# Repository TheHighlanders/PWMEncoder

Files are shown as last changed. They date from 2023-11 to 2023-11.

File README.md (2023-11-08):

# A Custom PWM Encoder for FRC
This encoder connects to a SparkMAX Motor Controller, using the Data Port. This encoder was designed with use on Swerve Drive Specialties Mk 4 Modules, with NEOs. 

These utilize the AS5047 chip to read a rotating magnetic field, and convert that to a PWM output.

Included in this repo are the KiCAD project files, as well as STEP file for the board, and 2 parts of a case that we used to mount these encoders.

## Important Notes

### Data Port Connector
In the project files, the Data Port connector is included on the incorrect side of the board. The pinouts for the board are correct, the only change that needs to be made if you use these is in assembly, the connector should be mounted on the top side (with the LED) of the board, and the notch should face away from the encoder IC.

### Programming the IC
The AS5047 encoder used here requires a programming process to output a PWM signal. A script to do this via an Arduino can be found here: [Programming Script](https://github.com/TheHighlanders/AS5047ProgrammingScript)

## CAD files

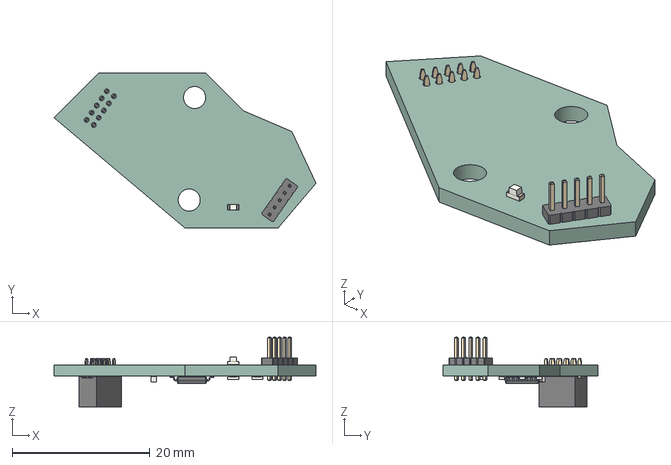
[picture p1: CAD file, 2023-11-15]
FRC6201PWMEncoder/6201PWM.step
38.0 x 22.5 x 10.1 mm
FRC6201PWMEncoder PCB

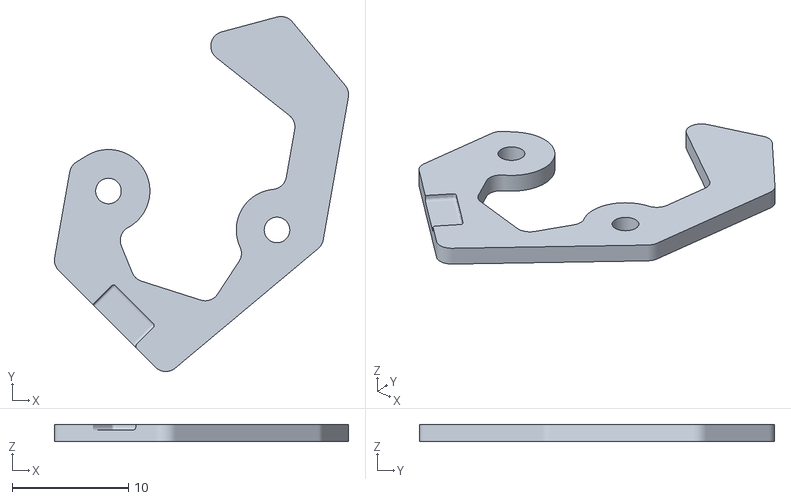
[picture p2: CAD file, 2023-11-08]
FRC6201PWMEncoder/EncoderCaseBottom.stl
25.3 x 30.5 x 1.50

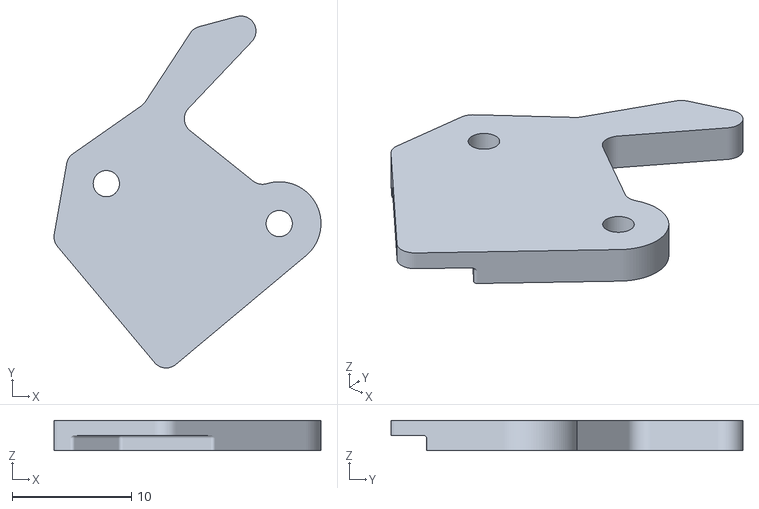
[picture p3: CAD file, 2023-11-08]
FRC6201PWMEncoder/EncoderCaseTop.stl
22.4 x 29.5 x 2.54

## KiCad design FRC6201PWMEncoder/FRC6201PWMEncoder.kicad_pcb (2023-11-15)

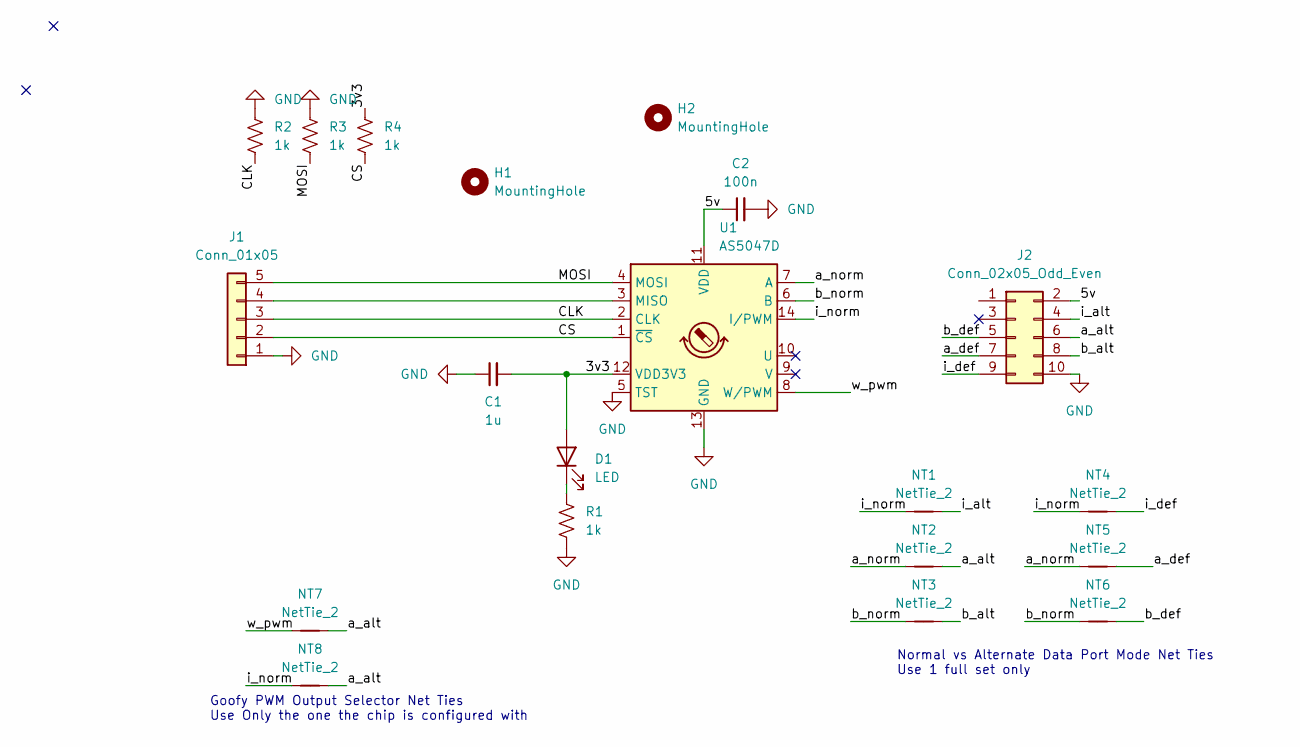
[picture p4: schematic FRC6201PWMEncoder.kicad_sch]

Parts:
C1: 1u; C_0603_1608Metric_Pad1.08x0.95mm_HandSolder
C2: 100n; C_0603_1608Metric_Pad1.08x0.95mm_HandSolder
D1: LED; LED_0603_1608Metric_Pad1.05x0.95mm_HandSolder
H1, H2: MountingHole; MountingHole_2.2mm_M2
J1: Conn_01x05; PinHeader_1x05_P1.27mm_Vertical
J2: Conn_02x05_Odd_Even; PinSocket_2x05_P1.27mm_Vertical
NT1, NT2, NT3, NT4, NT5, NT6, NT7, NT8: NetTie_2; Jumper
R1, R2, R3, R4: 1k; R_0603_1608Metric_Pad0.98x0.95mm_HandSolder
U1: AS5047D; TSSOP-14_4.4x5mm_P0.65mm

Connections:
/3v3: C1.2, D1.2 (A), R4.1, U1.12 (VDD3V3)
/5v: C2.1, J2.2, U1.11 (VDD)
/CLK: J1.3, R2.2, U1.2 (CLK)
/CS: J1.2, R4.2, U1.1 (~CS)
/MOSI: J1.5, R3.2, U1.4 (MOSI)
/a_alt: J2.6, NT2.2, NT7.2, NT8.2
/a_def: J2.7, NT5.2
/a_norm: NT2.1, NT5.1, U1.7 (A)
/b_alt: J2.8, NT3.2
/b_def: J2.5, NT6.2
/b_norm: NT3.1, NT6.1, U1.6 (B)
/i_alt: J2.4, NT1.2
/i_def: J2.9, NT4.2
/i_norm: NT1.1, NT4.1, NT8.1, U1.14 (I/PWM)
/w_pwm: NT7.1, U1.8 (W/PWM)
GND: C1.1, C2.2, J1.1, J2.10, R1.2, R2.1, R3.1, U1.5 (TST), U1.13 (GND)
unnamed: D1.1 (K), R1.1
unnamed: J1.4, U1.3 (MISO)

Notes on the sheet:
Goofy PWM Output Selector Net Ties Use Only the one the chip is configured with
Normal vs Alternate Data Port Mode Net Ties Use 1 full set only

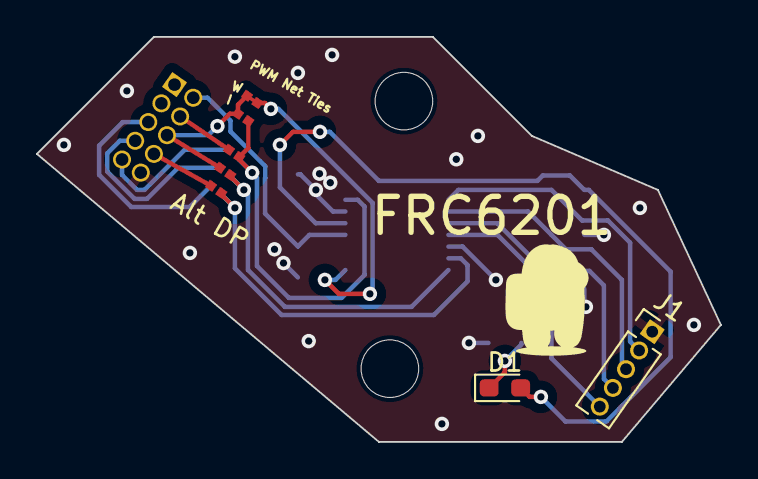
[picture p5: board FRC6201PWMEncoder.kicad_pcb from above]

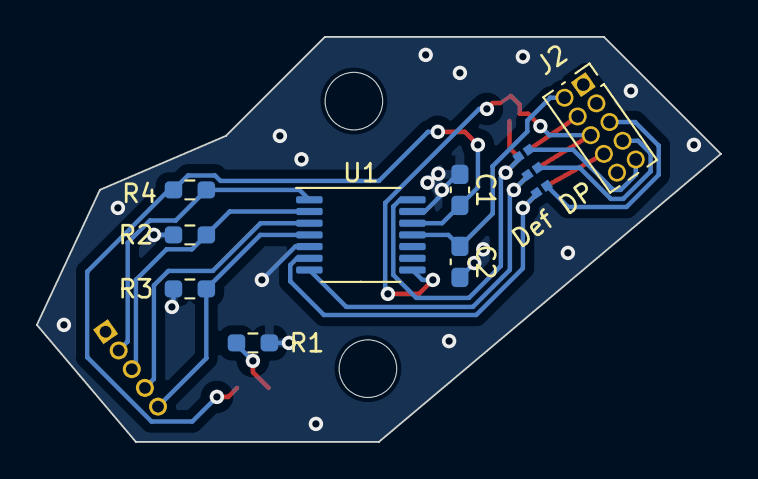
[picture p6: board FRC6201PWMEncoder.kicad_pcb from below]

Board: 2 copper layers, 38.0 x 22.5 mm, 18 parts (11 on the bottom side), 18 nets.

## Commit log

2023-11-08 Added Encoder Files
    [6201PWM.step, EncoderCaseBottom.stl, EncoderCaseTop.stl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]
2023-11-15 Increased Hole size to M3
    [6201PWM.step, FRC6201PWMEncoder.kicad_pcb]
